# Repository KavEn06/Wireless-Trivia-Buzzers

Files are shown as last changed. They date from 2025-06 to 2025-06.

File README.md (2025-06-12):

# Wireless-Trivia-Buzzers
### What is it?
There will be four buzzer boxes and one main box. Each buzzer box will represent a team (Teams A, B, C, and D) and will have four buttons, one for each player. The main box will house a screen that allows the host to see which player buzzed in first and will also include a reset button to clear all buzzes. For the time being, I plan to include two modes. The first mode allows only one player per team to buzz in, any player from the team can buzz, but only the first buzz from that team will register. The second mode is a free-for-all, where all 16 players can buzz in individually, regardless of their team.

### Backstory 
Basically this idea came to me while me and a couple of friends were practicing for a trivia competition that my school's Classics club hosts semi-annually (with other neighboring schools). I realised that many other schools didn't have the funds to buy the "official" buzzers that all the other schools use, which means that they just end up using some horrible online version, which are very dependent on how good your wifi is. Moreover, these buzzers we're SO HEAVY and annoying to set up that half the time my friends and I didn't even bother practicing because we were too lazy to set up the buzzers and get an actual competition environment going. 

## Architecture & Features 
### Hardware
- **Display:** 16x2 LCD With an I2C Module
- **Chip:** ESP32
- **Audio:**
  - **DAC:** MAX98357A
  - **Speakers:** 2W Speakers
- **Power:** 9V Battery or USB-C 

## Pictures 
### 3D Model 


### Wiring Diagram


### PCBs 
Buzzer Box 


Main Box 


## BOM 
| Item | Purpose  | Source | Price  | Inventory |
|---|---|---|---|---|
| 5x ESP32 (38 Pin) Dev Board | Controller | [Link](https://www.aliexpress.us/item/3256806817804530.html) | $32.10 | Owned |
| 16x2 LCD with I2C Module | Output | [Link](https://www.aliexpress.us/item/3256806005226729.html) | $3.47  | Owned |
| Speakers | Output | [Link](https://www.aliexpress.us/item/3256806149654655.html) | $2.99  | Owned |
| 5 LEDS | Output | [Link](https://lcsc.com/product-detail/LED-Indication-Discrete_Everlight-Elec-204-10SURD-S530-A3_C99772.html) | $0.50  | Owned |
| MAX98357A | Output | [Link](https://www.aliexpress.us/item/3256806882501015.html) | $2.53  | Owned |
| 17x Push Buttons | Input | [Link](https://www.aliexpress.us/item/4000097252595.html) | $10.25 | Owned |
| 16x Charger Wires (Any work)  | Input | [Link](https://www.aliexpress.us/item/3256806607225846.html) | $14.43 | Owned |
| Micro SD Card Module | Input | [Link](https://www.aliexpress.us/item/3256806271288304.html) | $1.28  | Highway Provided |
| 5x USB-C Port | Input | [Link](https://www.aliexpress.us/item/3256805808963500.html) | $4.11  | Owned |
| 5x 9V Battery | Power | [Link](https://www.amazon.com/dp/B00MH4QM1S) | $12.69 | Highway Provided |
| 5x 9V Battery Connector | Power | [Link](https://lcsc.com/product-detail/Battery-Holders-Clips-Contacts_Q-J-C70374_C70374.html) | $0.51  | Owned |
| 5x DC - DC Buck Converter | Power | [Link](https://www.aliexpress.us/item/3256807145249780.html) | $4.65  | Highway Provided |
| 5x 3 Way (SPDT) Switch | Switch | [Link](https://lcsc.com/product-detail/slide-switches_usakro-ss-12f15-g6_C698214.html) | $0.41  | Highway Provided |
| 2.54mm Headers | Connector| [Link](https://lcsc.com/product-detail/Female-Headers_Megastar-ZX-PM2-54-1-15PY_C7499333.html) | $0.84  | Highway Provided |
| Buzzer Box PCB (w/ Shipping) | PCB | JLCPCB | $10.00 | Highway Provided |
| Main Box PCB (w/ Shipping) | PCB | JLCPCB | $5.00  | Highway Provided |
| | | Total: | $105.76| |
| | | Total (Highway Provided): | $34.87 | |

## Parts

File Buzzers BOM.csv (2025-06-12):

Item | Purpose | Source | Price | Inventory
5x ESP32 (38 Pin) Dev Board | Controller | https://www.aliexpress.us/item/3256806817804530.html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 | $32.10 | Owned
16x2 LCD with I2C Module | Output | https://www.aliexpress.us/item/3256806005226729.html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 | $3.47 | Owned
Speakers | Output | https://www.aliexpress.us/item/3256806149654655.html?mp=1 | $2.99 | Owned
5 LEDS | Output | https://lcsc.com/product-detail/LED-Indication-Discrete_Everlight-Elec-204-10SURD-S530-A3_C99772.html | $0.50 | Owned
MAX98357A | Output | https://www.aliexpress.us/item/3256806882501015.html?mp=1 | $2.53 | Owned
17x Push Buttons | Input | https://www.aliexpress.us/item/4000097252595.html?mp=1 | $10.25 | Owned
16x Charger Wires (Any work) | Input | https://www.aliexpress.us/item/3256806607225846.html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 | $14.43 | Owned
Micro SD Card Module | Input | https://www.aliexpress.us/item/3256806271288304.html?mp=1 | $1.28 | Highway Provided
5x USB-C Port | Input | https://www.aliexpress.us/item/3256805808963500.html?mp=1 | $4.11 | Owned
5x 9V Battery | Power | https://www.amazon.com/Amazon-Basics-Performance-All-Purpose-Batteries/dp/B00MH4QM1S | $12.69 | Highway Provided
5x 9V Battery Connector | Power | https://lcsc.com/product-detail/Battery-Holders-Clips-Contacts_Q-J-C70374_C70374.html | $0.51 | Owned
5x DC - DC Buck Converter | Power | https://www.aliexpress.us/item/3256807145249780.html?mp=1 | $4.65 | Highway Provided
5x 3 Way (SPDT) Switch | Switch | https://lcsc.com/product-detail/slide-switches_usakro-ss-12f15-g6_C698214.html | $0.41 | Highway Provided
2.54mm Headders | Connector | https://lcsc.com/product-detail/Female-Headers_Megastar-ZX-PM2-54-1-15PY_C7499333.html | $0.84 | Highway Provided
Buzzer Box PCB (w/ Shipping) | PCB | JLCPCB | $10.00 | Highway Provided
Main Box PCB (w/ Shipping) | PCB | JLCPCB | $5.00 | Highway Provided
 |  | Total: | $105.76
 |  | Total (Highway Provided): | $34.87

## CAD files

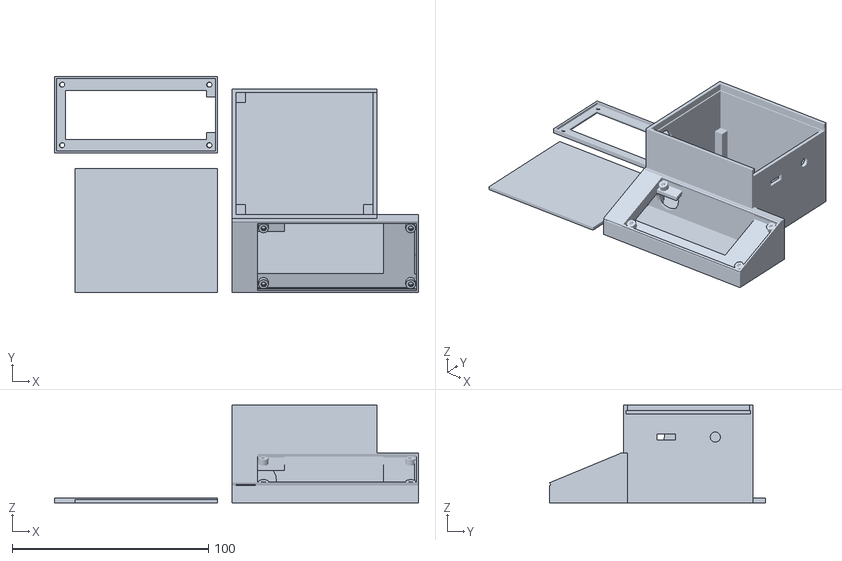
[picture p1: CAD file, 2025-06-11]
CAD/MainBox.stl
185.5 x 109.9 x 49.9

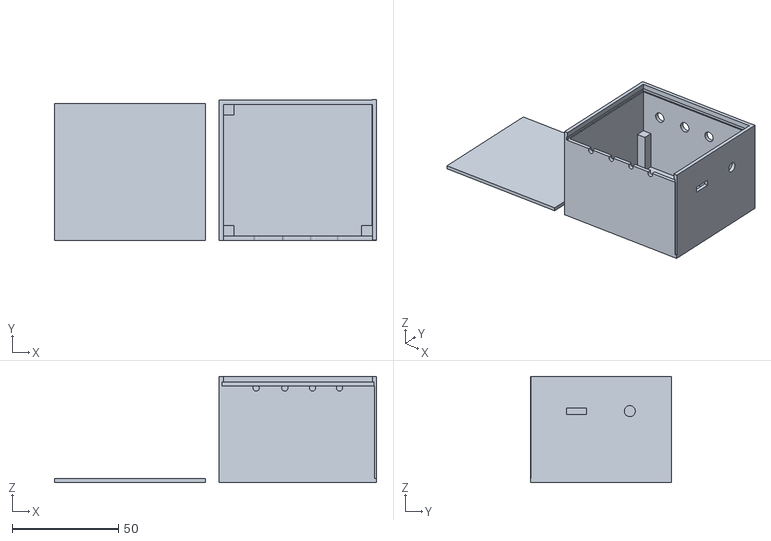
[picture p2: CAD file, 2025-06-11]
CAD/BuzzerBox.stl
151.5 x 66.2 x 49.9

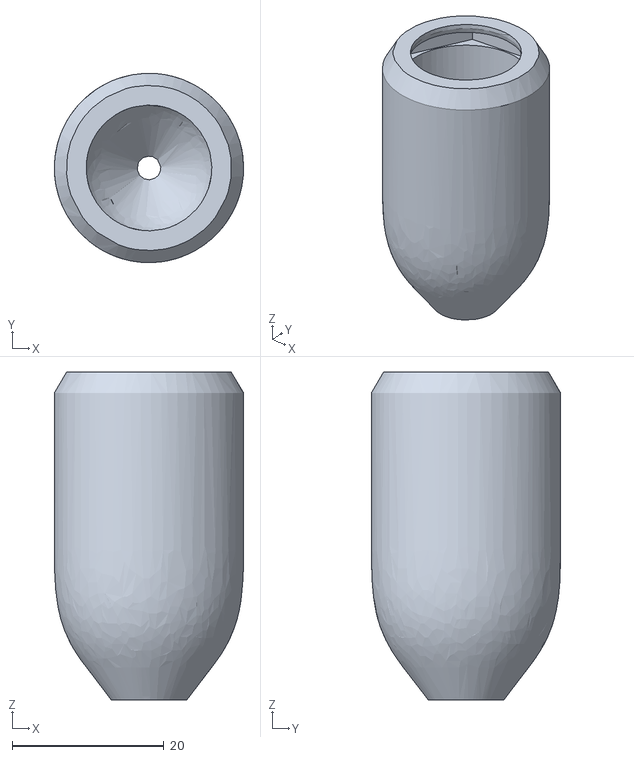
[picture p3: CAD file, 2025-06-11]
CAD/BuzzerHandle.stl
25.0 x 25.0 x 43.3

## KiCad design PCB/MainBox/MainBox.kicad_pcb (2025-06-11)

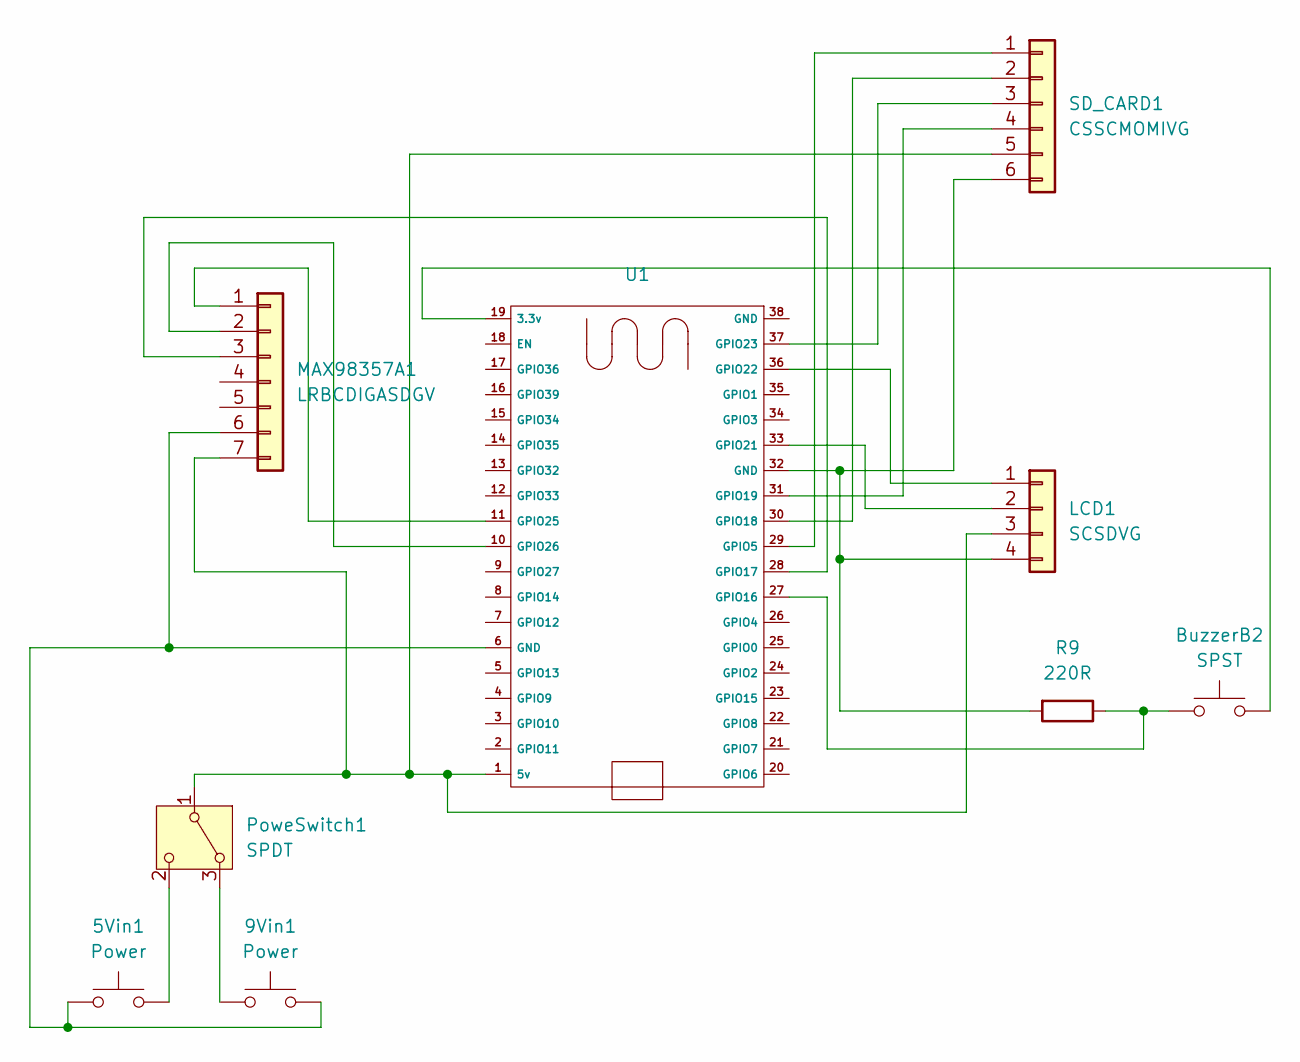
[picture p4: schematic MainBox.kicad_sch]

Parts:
5Vin1, 9Vin1: Power; SW_PUSH_1P1T_6x3.5mm_H4.3_APEM_MJTP1243
BuzzerB2: SPST; SW_PUSH_1P1T_6x3.5mm_H4.3_APEM_MJTP1243
LCD1: SCSDVG; PinSocket_1x04_P2.54mm_Vertical
MAX98357A1: LRBCDIGASDGV; MAX98357A
PoweSwitch1: SPDT; SW_Slide-03_Wuerth-WS-SLTV_10x2.5x6.4_P2.54mm
R9: 220R; R_Axial_DIN0204_L3.6mm_D1.6mm_P7.62mm_Horizontal
SD_CARD1: CSSCMOMIVG; Micro SD Card Module
U1: ESP32_38pin

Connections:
unnamed: LCD1.1, U1.36 (GPIO22)
unnamed: LCD1.2, U1.33 (GPIO21)
unnamed: LCD1.3, MAX98357A1.7, PoweSwitch1.1 (B), SD_CARD1.5, U1.1 (5v)
unnamed: LCD1.4, R9.2, SD_CARD1.6, U1.32 (GND)
unnamed: MAX98357A1.1, U1.11 (GPIO25)
unnamed: MAX98357A1.2, U1.10 (GPIO26)
unnamed: MAX98357A1.3, U1.28 (GPIO17)
unnamed: 5Vin1.1, 9Vin1.1, MAX98357A1.6, U1.6 (GND)
unnamed: 9Vin1.2, PoweSwitch1.3 (A)
unnamed: 5Vin1.2, PoweSwitch1.2 (C)
unnamed: SD_CARD1.1, U1.29 (GPIO5)
unnamed: SD_CARD1.2, U1.30 (GPIO18)
unnamed: SD_CARD1.3, U1.37 (GPIO23)
unnamed: SD_CARD1.4, U1.31 (GPIO19)
unnamed: BuzzerB2.2, U1.19 (3.3v)
unnamed: BuzzerB2.1, R9.1, U1.27 (GPIO16)

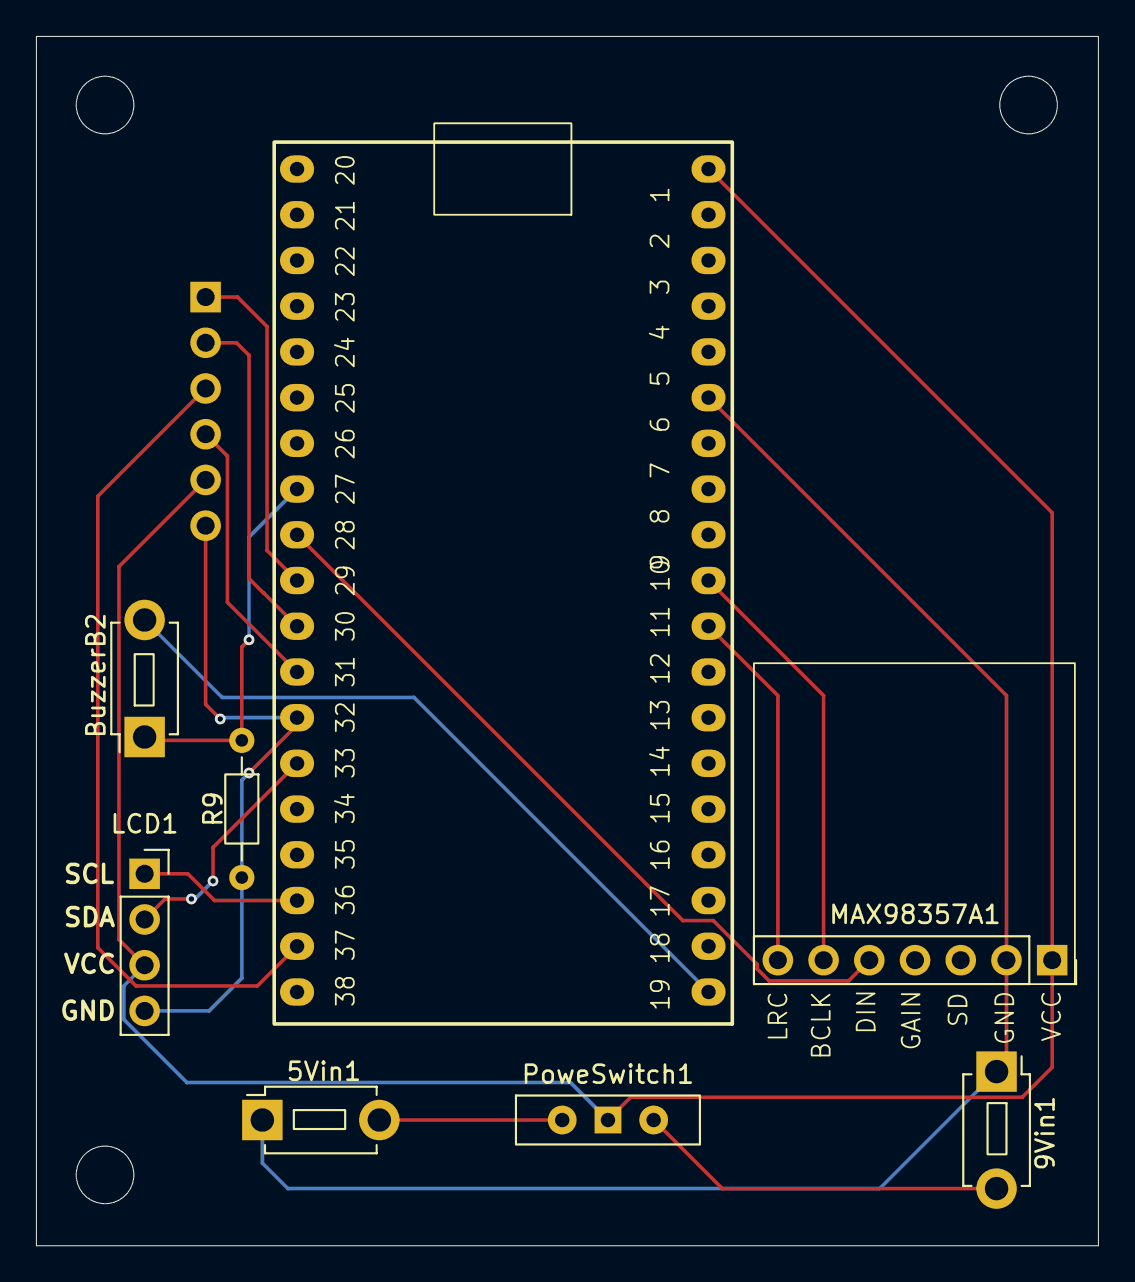
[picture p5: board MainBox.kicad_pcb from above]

Board: 2 copper layers, 59.0 x 67.2 mm, 9 parts (1 on the bottom side), 16 nets.

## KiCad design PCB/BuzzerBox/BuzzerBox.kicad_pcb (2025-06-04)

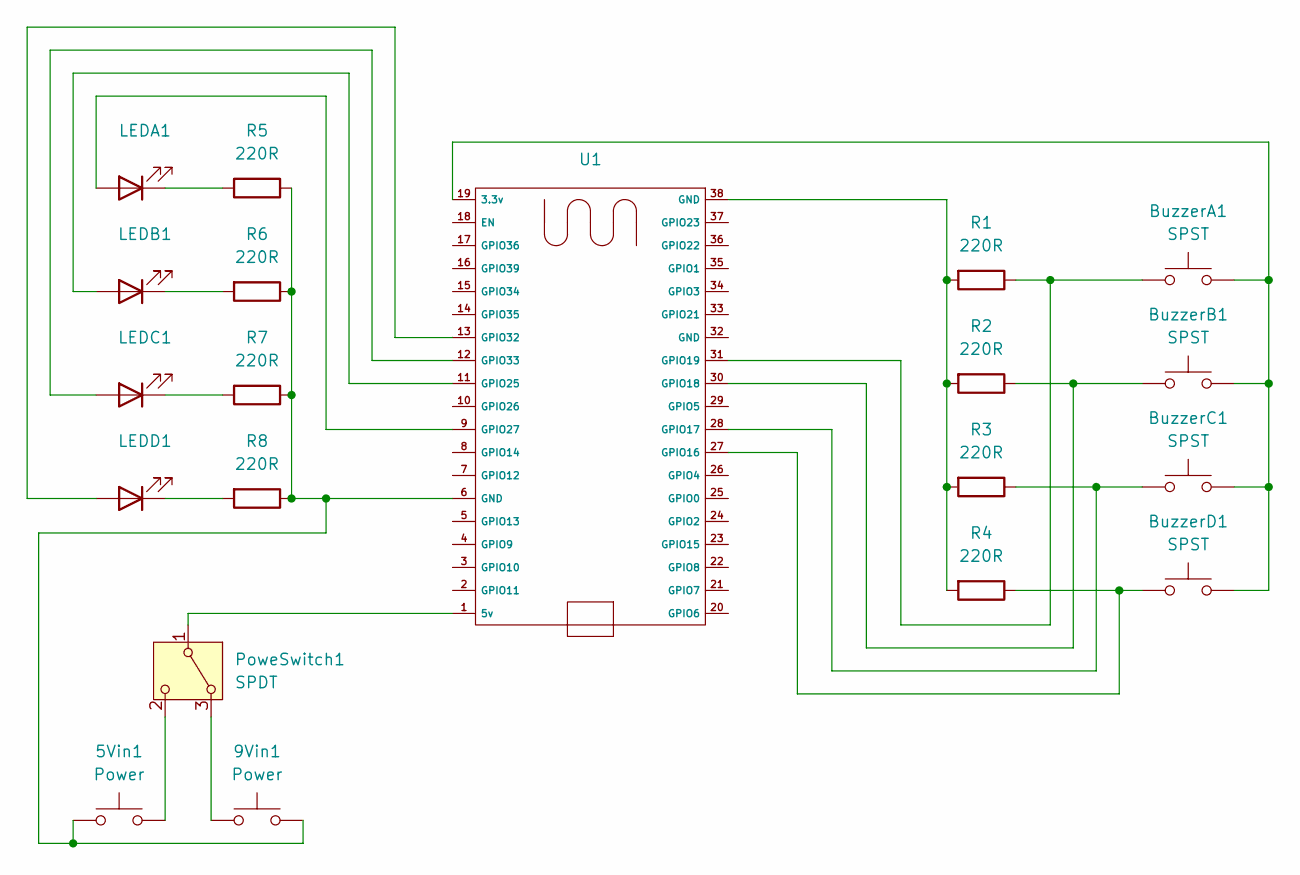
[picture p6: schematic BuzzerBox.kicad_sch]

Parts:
5Vin1, 9Vin1: Power; SW_PUSH_1P1T_6x3.5mm_H4.3_APEM_MJTP1243
BuzzerA1: SPST; SW_PUSH_1P1T_6x3.5mm_H4.3_APEM_MJTP1243
BuzzerB1: SPST; SW_PUSH_1P1T_6x3.5mm_H4.3_APEM_MJTP1243
BuzzerC1: SPST; SW_PUSH_1P1T_6x3.5mm_H4.3_APEM_MJTP1243
BuzzerD1: SPST; SW_PUSH_1P1T_6x3.5mm_H4.3_APEM_MJTP1243
LEDA1: LED_D5.0mm
LEDB1: LED_D5.0mm
LEDC1: LED_D5.0mm
LEDD1: LED_D5.0mm
PoweSwitch1: SPDT; SW_Slide-03_Wuerth-WS-SLTV_10x2.5x6.4_P2.54mm
R1, R2, R3, R4, R5, R6, R7, R8: 220R; R_0805_2012Metric; LCSC C17557
U1: ESP32_38pin

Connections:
unnamed: 5Vin1.1, 9Vin1.1, R5.1, R6.1, R7.1, R8.1, U1.6 (GND)
unnamed: LEDA1.2 (A), U1.9 (GPIO27)
unnamed: LEDA1.1 (K), R5.2
unnamed: LEDB1.2 (A), U1.11 (GPIO25)
unnamed: LEDB1.1 (K), R6.2
unnamed: LEDC1.2 (A), U1.12 (GPIO33)
unnamed: LEDC1.1 (K), R7.2
unnamed: LEDD1.2 (A), U1.13 (GPIO32)
unnamed: LEDD1.1 (K), R8.2
unnamed: 9Vin1.2, PoweSwitch1.3 (A)
unnamed: PoweSwitch1.1 (B), U1.1 (5v)
unnamed: 5Vin1.2, PoweSwitch1.2 (C)
unnamed: R1.2, R2.2, R3.2, R4.2, U1.38 (GND)
unnamed: BuzzerA1.2, BuzzerB1.2, BuzzerC1.2, BuzzerD1.2, U1.19 (3.3v)
unnamed: BuzzerD1.1, R4.1, U1.27 (GPIO16)
unnamed: BuzzerC1.1, R3.1, U1.28 (GPIO17)
unnamed: BuzzerB1.1, R2.1, U1.30 (GPIO18)
unnamed: BuzzerA1.1, R1.1, U1.31 (GPIO19)

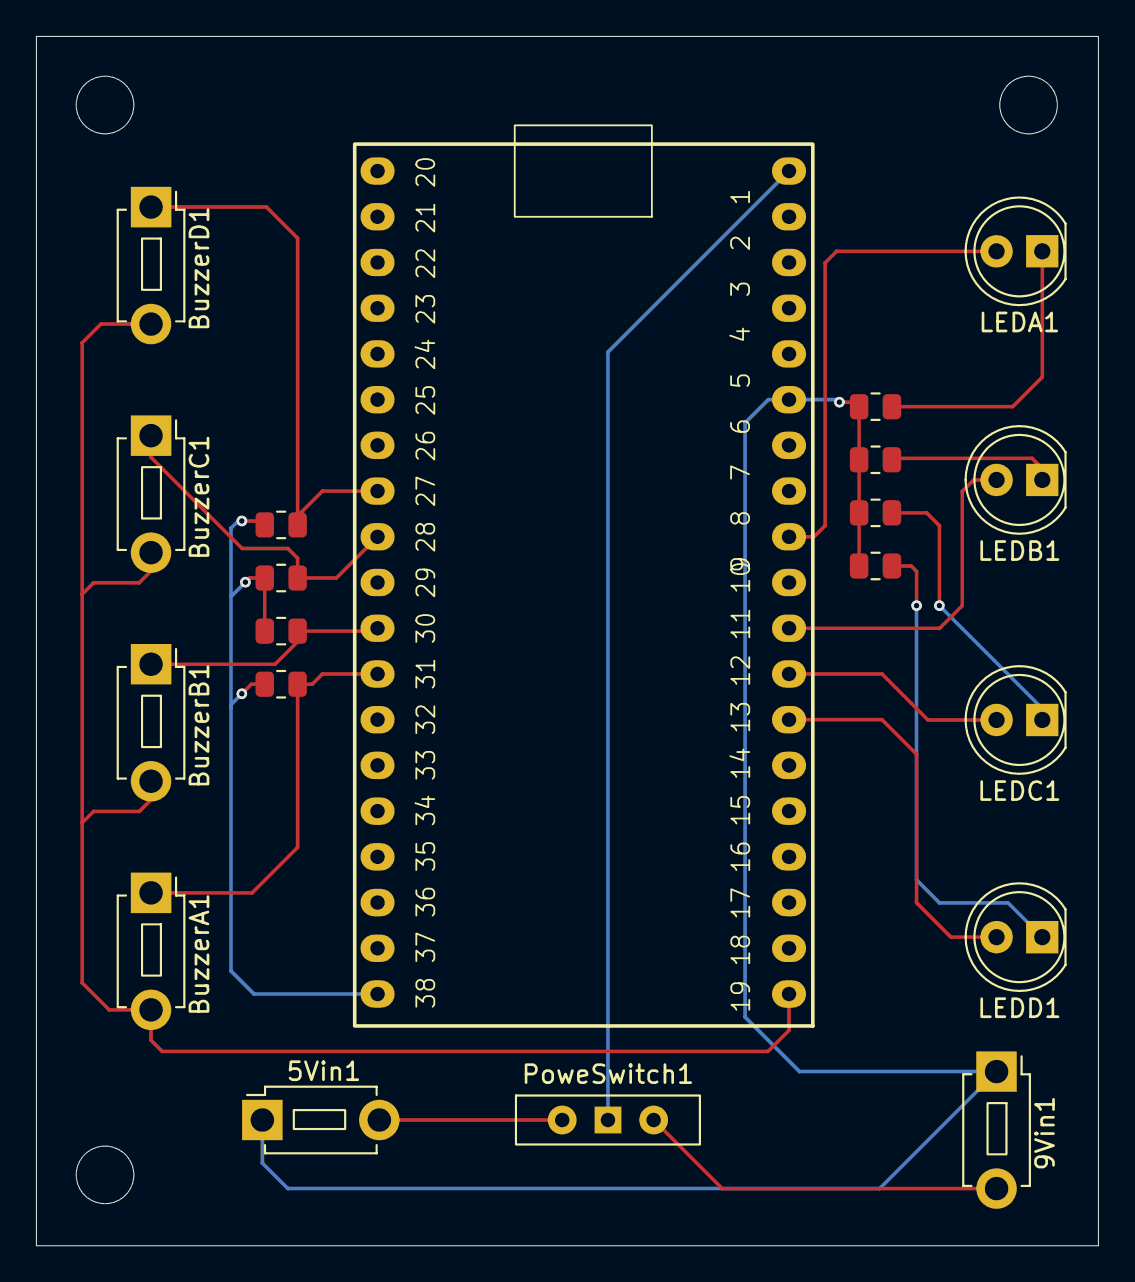
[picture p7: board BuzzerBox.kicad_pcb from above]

Board: 2 copper layers, 59.0 x 67.2 mm, 20 parts (0 on the bottom side), 18 nets.

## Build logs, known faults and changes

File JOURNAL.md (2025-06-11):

---
title: "Wireless Trivia Buzzers"
author: "KavEn06"
description: "Wireless trivia buzzers that can have up to a team of 4. They're designed to be portable, which means that you can take them anywhere you want!!!"
created_at: "2025-05-24"
---

# Buzzer Creation Journal 
## Total Time Spent: 15.5 Hours

## 05-24-2025: Planning 
### Backstory (kinda)
Basically this idea came to me while me and a couple of friends were practicing for a trivia competition that my school's Classics club hosts semi-annually (with other neighboring schools). I realised that many other schools didn't have the funds to buy the "official" buzzers that all the other schools use, which means that they just end up using some horrible online version, which are very dependent on how good your wifi is. Moreover, these buzzers we're SO HEAVY and annoying to set up that half the time my friends and I didn't even bother practicing because we were too lazy to set up the buzzers and get an actual competition environment going. 

### What is it?
There will be four buzzer boxes and one main box. Each buzzer box will represent a team (Teams A, B, C, and D) and will have four buttons, one for each player. The main box will house a screen that allows the host to see which player buzzed in first and will also include a reset button to clear all buzzes. For the time being, I plan to include two modes. The first mode allows only one player per team to buzz in, any player from the team can buzz, but only the first buzz from that team will register. The second mode is a free-for-all, where all 16 players can buzz in individually, regardless of their team.

### Tech
* All 4 buzzer boxes and the main box will be controlled by an ESP-32 and will communicate with each other using ESPNOW
* All the boxes will be battery powered (now that I type this, I realise that a USB-C port would be nice so that the buzzers have another power source)
* Each buzzer box will have four LEDs that light up depending on which player buzzes in
* For the screen on the main box, it will be a 16x2 LCD with an I2C module



### Things Todo
* Deciding if implementing speakers into the main box is feasible
* What type of battery to use (AA or rechargeable)
* Designing the PCB
* Deciding how I want the boxes to look (maybe like an old Mac or just a plain old box to house the electronics)
* Designing the enclosures

**Total time spent: 4h**

## 05-25-2025: Circuit Design & BOM 
### Circuit Design (Changes) 
* Implemented 9V power source (stepped down to 5V) and 5V USB-C input, controlled by a SPDT switch
* Added MAX98357A amp, 2 speakers and a micro SD card module (so that the buzzer can actually "buzz" when a player buzzes in)



### BOM (Unfinished) 
| Item | Purpose | Source | Price |
|---|---|---|---|
| 5x ESP32 (38 Pin) Dev Board | Controller | | |
| 16x2 LCD with I2C Module | Output | | |
| Speakers | Output | | |
| 17x Push Buttons | Input | | |
| 16x Charger Wires (Any work) | Input | | |
| Micro SD Card Module | Input | | |  
| 5x 9V Battery | Power | | |
| 5x 9V Battery Connector | Power | | |
| 5x DC - DC Buck Converter | Power | | |
| 5x 3 Way (SPDT) Switch | Switch | | |
| 4x Buzzer Box PCB | PCB | | |
| 1x Main Box PCB | PCB | | |

### Things Todo
* Designing the 2 PCBS on KiCAD
* Making the enclosures
* Coding the main and buzzer boxes

**Total time spent: 2.5h**

## 05-27-2025: Buzzer Box PCB 
### KiCAD
* Learned how to use KiCAD for the first time and created the PCB for the buzzer box


**Total time spent: 2h**

## 06-04-2025: More Circuit Design 
### Main Buzzer PCB
- Finished the main buzzer PCB and made sure that the SD module, MAX98357A, and DC-DC buck converter can all fit in the same footprint as the PCB (so it doesn't take up any extra room in the box)
- I didn't bother with silkscreen art for the main box, as both sides have markings that show where the other boards connect to
- The normal buzzer PCBs didn't get silkscreen because I was just too dead to learn it after spending 2 hours trying to figure my way through KiCAD 💀💀💀
- On a separate note, this PCB, I learned how to make custom symbols and footprints 

(The connectors for the SD card module are on the back of the board on the same side that the 9V battery is going to be on)

### Things Todo
- I have to make 2 simple boxes to house the components for both types of boxes
- I have already started on some basic ESP-NOW code to get various boxes working between each other, but I still have to implement the actual buzzer rules
- For the code for the main box, I have to add code to read files from the SD card and play it through the speakers
- Then I can submit my application!!!!!! 

**Total time spent: 2h**

## 06-10-2025: SUBMITTING AN APPLICATION SPEEDRUNNNNNN!!!!!! 
### CADing up the Boxes 
I used TinkerCAD to make the boxes for the buzzers. I could have done it on something like OnShape, but the design was just a simple box, and there were no special fillets or anything of that sort, so I decided to do it in TinkerCAD (and it just required less critical thinking). 
List of what I made: 
- Little handle for the buzzer button
- For the normal buzzer boxes, it's just a simple box with 4 holes to allow the buzzer wires to escape and a usb c input, and a 3-way switch
- For the main buzzer box, it has a mount for the 16x2 LCD, a hole for a reset button and a usb c input, and a 3-way switch


### Programming the Boxes
Since I already have the ESP32's on me, I was able to do most of the coding and semi verify that they work. For the buzzer box code, it was quite simple, as it just sends which buzzer has buzzed to the main box and lights up the corresponding light on the box itself. The main box was slightly more complex as it needed to accept the information that was sent from 4 buzzer boxes and display it on the LCD. Furthermore, the main box also needs to open the .mp3 file from the sd card and play the "buzz" sound everytime someone buzzes in. I honestly don't know if the whole audio section of the code will work because I have none of the components on hand, but I have looked through countless forums and most people have done audio on an ESP32 in a pretty similar way, so I have hope!!!!!

**Total time spent: 5h**

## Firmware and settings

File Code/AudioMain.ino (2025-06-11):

// include libraries
#include <esp_now.h>
#include <WiFi.h>
#include <LiquidCrystal_PCF8574.h>
#include <FS.h>
#include <SD.h>
#include <SPI.h>
#include <AudioFileSourceSD.h>
#include <AudioGeneratorMP3.h>
#include <AudioOutputI2S.h>

// setting up the variables for reset button
#define reset 16

// SD card chip pin 
#define SD_CS_PIN 5  

AudioGeneratorMP3 *mp3;
AudioFileSourceSD *file;
AudioOutputI2S *out;

// variable for storing the button status
int statereset = 0;
int ind = 0; 
String buttons[4]; 
bool Apress = false; 
bool Bpress = false; 
bool Cpress = false; 
bool Dpress = false; 

// MAC address' of buzzers
uint8_t teamA[] = { 0xA8, 0x42, 0xE3, 0xBC, 0x72, 0xF8 };
uint8_t teamB[] = { 0xE4, 0x65, 0xB8, 0x79, 0x78, 0xB0 };
uint8_t teamC[] = { 0xA0, 0xA3, 0xB3, 0xAB, 0x84, 0x24 };
uint8_t teamD[] = { 0xE4, 0x65, 0xB8, 0x79, 0x82, 0xD0 };

// define I2C address for 16x2 LCD
#define I2C_ADDR 0x27
LiquidCrystal_PCF8574 lcd(I2C_ADDR);

// data structure
typedef struct buttonpress {
  String button;
} buttonpress;

// create a structured object
buttonpress myData;

// peer info
esp_now_peer_info_t peerInfo;

// callback function when data is sent
void OnDataSent(const uint8_t *mac_addr, esp_now_send_status_t status) {
  Serial.print("\r\nLast Packet Send Status:\t");
  Serial.println(status == ESP_NOW_SEND_SUCCESS ? "Delivery Success" : "Delivery Fail");
}
// callback functions when data is received
void OnDataRecv(const esp_now_recv_info *recv_info, const uint8_t *incomingData, int len) {
  const uint8_t* mac = recv_info->src_addr; 
  memcpy(&myData, incomingData, sizeof(myData));
  Serial.print("Data received: ");
  Serial.println(len);
  Serial.println("Button: ");
  Serial.println(myData.button);
  buttonSelect(myData.button); 
}

// buzzed button void method 
void buttonSelect(String button) {
  if (button[0] == 'A' && !Apress) {
    Apress = true; 
    buttons[ind] = button; 
    ind++;
  } 
  else if (button[0] == 'B' && !Bpress) {
    Bpress = true;
    buttons[ind] = button;
    ind++;
  }
  else if (button[0] == 'C' && !Cpress) {
    Cpress = true;
    buttons[ind] = button;
    ind++;
  }
  else if (button[0] == 'D' && !Dpress) {
    Dpress = true;
    buttons[ind] = button;
    ind++;
  }
  playMP3("/buzz.mp3");
}

// audio void method 
void playMP3(const char* filename) {
  // stop playing mp3 if there is one playing currently 
   if (mp3->isRunning()) {
    mp3->stop();
  }

  // delete whatever file was used previously 
  if (file) {
    delete file;
    file = nullptr;
  }

  // create new file for the current audio 
  file = new AudioFileSourceSD(filename);
  if (!file || !file->isOpen()) {
    Serial.println("Failed to open file!");
    return;
  }

  // play current audio
  if (!mp3->begin(file, out)) {
    Serial.println("Failed to begin MP3 playback.");
  } else {
    Serial.println("Playback started.");
  }
}

void setup() {
  Serial.begin(115200);
  WiFi.mode(WIFI_STA);
  Wire.begin();

  // initialize the LCD
  lcd.begin(16, 2);
  lcd.setBacklight(255); 

  // initializing the button pins as input
  pinMode(reset, INPUT);

  // initilize esp-now
  if (esp_now_init() != ESP_OK) {
    Serial.println("Error initializing ESP_NOW");
    return;
  }

  // register received callback
  esp_now_register_recv_cb(OnDataRecv);

  // register send callback
  esp_now_register_send_cb(OnDataSent);

  // register peer
  peerInfo.channel = 0;
  peerInfo.encrypt = false;

  // add buzzer A as peer 
  memcpy(peerInfo.peer_addr, teamA, 6);
  if (esp_now_add_peer(&peerInfo) != ESP_OK) {
    Serial.println("Failed to add peer");
    return;
  }

  // add buzzer B as peer 
  memcpy(peerInfo.peer_addr, teamB, 6);
  if (esp_now_add_peer(&peerInfo) != ESP_OK) {
    Serial.println("Failed to add peer");
    return;
  }

  // add buzzer C as peer 
  memcpy(peerInfo.peer_addr, teamC, 6);
  if (esp_now_add_peer(&peerInfo) != ESP_OK) {
    Serial.println("Failed to add peer");
    return;
  }

  // add buzzer D as peer 
  memcpy(peerInfo.peer_addr, teamD, 6);
  if (esp_now_add_peer(&peerInfo) != ESP_OK) {
    Serial.println("Failed to add peer");
    return;
  }

   // Mount SD card
  if (!SD.begin(SD_CS_PIN)) {
    Serial.println("SD card mount failed!");
    while (1);
  }
  Serial.println("SD card initialized.");

  // Set up I2S for MAX98357A
  out = new AudioOutputI2S();
  out->SetPinout(26, 25, 17);  // BCLK, LRC, DIN
  out->SetGain(1.0);           // Max volume

  // Open MP3 and play as a test for startup 
  mp3 = new AudioGeneratorMP3(); // just once in setup
  playMP3("/buzz.mp3");
}

void loop() {
  statereset = digitalRead(reset);

  lcd.setCursor(0, 0);
  lcd.print("Buttons:");

  String displayText = "";
  for (int i = 0; i < ind; i++) {
    displayText += buttons[i] + " ";
  }
  lcd.setCursor(0, 1);
  lcd.print(displayText); 

  if (statereset == HIGH) {
    myData.button = "clear";
    esp_now_send(0, (uint8_t *)&myData, sizeof(myData));
    ind = 0; 

    Apress = false; 
    Bpress = false; 
    Cpress = false; 
    Dpress = false; 

    for (int i = 0; i < 4; i++) {
      buttons[i] = "";
    }
  }

  delay(500);
  lcd.clear();
}

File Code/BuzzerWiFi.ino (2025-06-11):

// include libraries 
#include <esp_now.h>
#include <WiFi.h> 

// variables 
int int_value; 

// setting up the variables for buzzer buttons 
#define Button1 16 
#define Button2 17
#define Button3 18
#define Button4 19
const int led1 = 27; 
const int led2 = 25; 
const int led3 = 33; 
const int led4 = 32; 

// variable for storing the button status 
int stateButton1 = 0;
int stateButton2 = 0;
int stateButton3 = 0;
int stateButton4 = 0;

bool press1 = false; 
bool press2 = false; 
bool press3 = false; 
bool press4 = false; 

// MAC address of main 
uint8_t broadcastAddress[] = {0xFC, 0xB4, 0x67, 0x74, 0x2F, 0x0C}; 

// data structure
typedef struct buttonpress {
  String button; 
} buttonpress;

// create a structured object 
buttonpress myData; 

// peer info 
esp_now_peer_info_t peerInfo; 

// callback functionfor when data is sent 
void OnDataSent(const uint8_t *mac_addr, esp_now_send_status_t status) {
  Serial.print("\r\nLast Packet Send Status:\t"); 
  Serial.println(status == ESP_NOW_SEND_SUCCESS ? "Delivery Success" : "Delivery Fail");
}

// callback functions when data is received
void OnDataRecv(const esp_now_recv_info *recv_info, const uint8_t *incomingData, int len) {
  const uint8_t* mac = recv_info->src_addr; 
  memcpy(&myData, incomingData, sizeof(myData));

  if (myData.button == "clear") {
    clearButtons(); 
  }
}

void clearButtons () {
  press1 = false; 
  Serial.print("Button 1: ");
  Serial.println(press1);
  digitalWrite(led1, LOW);
  press2 = false; 
  Serial.print("Button 2: ");
  Serial.println(press2);
  digitalWrite(led2, LOW);
  press3 = false; 
  Serial.print("Button 3: ");
  Serial.println(press3);
  digitalWrite(led3, LOW);
  press4 = false; 
  Serial.print("Button 4: ");
  Serial.println(press4);
  digitalWrite(led4, LOW);
}

void setup() {
  Serial.begin(115200); 
  WiFi.mode(WIFI_STA);

  // initializing the button pins as input and led pins as output 
  pinMode(Button1, INPUT);
  pinMode(Button2, INPUT);
  pinMode(Button3, INPUT);
  pinMode(Button4, INPUT);
  pinMode(led1, OUTPUT);
  pinMode(led2, OUTPUT);
  pinMode(led3, OUTPUT);
  pinMode(led4, OUTPUT);

  // initilize esp-now 
  if (esp_now_init() != ESP_OK) {
    Serial.println("Error initializing ESP_NOW");
    return;
  }

  // register received callback
  esp_now_register_recv_cb(OnDataRecv);

  // register send callback 
  esp_now_register_send_cb(OnDataSent);

  // register peer 
  memcpy(peerInfo.peer_addr, broadcastAddress, 6); 
  peerInfo.channel = 0;
  peerInfo.encrypt = false; 

  // add peer 
  if (esp_now_add_peer(&peerInfo) != ESP_OK) {
    Serial.println("Failed to add peer");
    return;
  }
}

void loop() {
  stateButton1 = digitalRead(Button1);
  stateButton2 = digitalRead(Button2);
  stateButton3 = digitalRead(Button3);
  stateButton4 = digitalRead(Button4);

  if (stateButton1 == HIGH && press1 == false) {
    // turn LED on
    digitalWrite(led1, HIGH);
    Serial.println("Button1");
    myData.button = "A1";
    esp_err_t result = esp_now_send(broadcastAddress, (uint8_t *) &myData, sizeof(myData));
    press1 = true; 
    
  }
  else if (stateButton2 == HIGH && press2 == false) {
    // turn LED on
    digitalWrite(led2, HIGH);
    Serial.println("Button2");
    myData.button = "B1";
    esp_err_t result = esp_now_send(broadcastAddress, (uint8_t *) &myData, sizeof(myData));
    press2 = true; 
  } 
  else if (stateButton3 == HIGH && press3 == false) {
    // turn LED on
    digitalWrite(led3, HIGH);
    Serial.println("Button3");
    myData.button = "C1";
    esp_err_t result = esp_now_send(broadcastAddress, (uint8_t *) &myData, sizeof(myData));
    press3 = true; 
  }
  else if (stateButton4 == HIGH && press4 == false) {
    // turn LED on
    digitalWrite(led4, HIGH);
    Serial.println("Button4");
    myData.button = "D1";
    esp_err_t result = esp_now_send(broadcastAddress, (uint8_t *) &myData, sizeof(myData));
    press4 = true; 
  }
  else {
    stateButton1 = 0;
    stateButton2 = 0;
    stateButton3 = 0;
    stateButton4 = 0;
  }

  //if (result == ESP_OK) {
  //  Serial.println("Sent");
  //}
  //else {
  //  Serial.println("Didn't go through");
  //}

}

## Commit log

2025-05-27 Make PCB Folder
2025-05-27 Buzzer Box PCB
    [BuzzerBox.kicad_pcb]
2025-06-04 PCB Files
    [BuzzerBox.kicad_pcb, MainBox.kicad_pcb]
2025-06-12 Update Buzzers BOM.csv
    [Buzzers BOM.csv]
